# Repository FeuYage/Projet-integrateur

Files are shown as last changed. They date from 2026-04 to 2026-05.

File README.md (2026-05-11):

# Projet Trottinette électrique

Ce projet est concu conjointement par Jérémy Roy, Arthur Méot, l'équipe professorale du 
Cégep de Sherbrooke et Écomobilité Sherbrooke par l'intermédiaire de M.Gauthier

L'objectif est la création d'un tableau de bord à l'aide d'un PCB de notre conception faisant
le lien entre le controlleur d'une trottinette électrique et un Rasberry Pi 3 servant à l'affichage sur un 
écran HDMI.

Ce projet a pour but de permettre aux étudiants de travailler sur un système réel et intégré plutôt que 
sur des montages de laboratoire isolés et théorique.

## Fonctionnalités requises
Le projet devra présenter les aspects suivant tel qu'exigé par Écomobilité Sherbrooke:
- L'affichage en temps réel des données en provenance de la trottinette
- Une interface ergonomique 
- Fixation au guidon par un boitier imprimé en 3D
- Présence d'un manuel utilisateur
- Restrictions de composantes imposé par le client. (Voir prérequis)

## Prérequis

### Matériel
- Base de trottinette fonctionnel fournit par le client
- Rasberry Pi 3
- Écran compatible avec la communication HDMI (Rasberry Pi)
- Cable JST 10 pins à JST 10 pins (PCB STM32)
- Cables à breadboard femelle à femelles (PCB STM32 / Rasberry Pi)
- PCB concu par les étudiants (PCB STM32)
- Boitier fixable sur le guidon de la trottinette (Boitier 3D)

### Logiciel
- Grisement lors du freinage (Rasberry Pi)
- Affichage du mode de conduite (Rasberry Pi)
- Arrêt de l'accélération moteur lors du freinage (Rasberry Pi)
- Affichage en temps réel des données (Rasberry Pi)
- Interface ergonomique (Rasberry Pi)
- Réception données sous format UART (STM32)

### Limitations
- Le PCB doit être programmable par le connecteur USB-C
- Nous devons avoir un bouton reset dédié sur le PCB
- Nous devons utiliser la puce STM32U083MC 
- Power supply 5V de 2.5A pour l'alimentation du Rasberry Pi 4 model B
- Les Dels utiliser doivent utiliser de 5mA
- Alimentation maximale de 12V/0.5A
- La réception des données se fait par le format JSON sur un protocol UART en provenance du controleur 
- Dût à notre installation actuelle avec un écran HDMI, la station et fixe et ne peux pas être fixé sur la trottinette
- Le système ne possède présentement pas de sécurité en cas de chute qui stopperait le moteur.
- Le système ne peut fonctionner sur l'alimentation de la batterie car il n'y a plus de convertisseur à la sortie du 12V.

## Structure

### Schéma
Voir section "PCB" -> "Schémas" pour voir les schémas de concept et électrique du projet.

### Dossiers/codes
Voir section "Codes" pour visionner les codes nécessaire au fonctionnement du projet.
#### Section Rasberry Pi 
- Ce code est à insérer dans un Rasberry Pi 4 model B et sert à l'affichage des données traitées par le STM32 sous format UART ou I2C sur un écran par l'intermédiaire d'un port HDMI.
#### Section STM32
- Ce code est à insérer dans le module STM32 conçu pour ce projet est fait le traitement des données reçu en provenance du controlleur de la trottinette.  Il recoit des informations par UART sous le format JSON et les retourne par UART et I2C.  

### Tests/validation
[Plan_Test](https://github.com/FeuYage/Projet-integrateur/tree/main/PCB/Plan%20de%20test)

## Utilisation

### Pour un utilisateur
- Lors du démarrage, passage par 2 modes : initialisation / mode conduite.
- En mode conduite, l'utilisateur à accès à : Freins / Accélération / Interrupteur des lumières / Informations affichées sur l'écran (Vitesse en km/h, niveau charge batterie, état freins, indicateur de la clé, température drive, mode de vitesse, état lumière, état arrêt urgence)
- L'utilisateur n'a pas d'accès aux éléments de débuggages.

### Pour un developpeur
- Mettre le jumper sur les broches BOOT du PCB pour entrer dans le mode de démarrage programmation par USB OU, Brancher le port JTAG pour programmation.
- Programmation faite par l'intermédiaire du port USB-C ou JTAG du PCB fait par les étudiants et en passent par la logiciel CUBEIDE pour modification du code accessible dans la section STM32.
- Plusieurs éléments de débuggages sont présent sur le PCB pour diagnostiquer toutes erreurs possibles.  Les dels servent pour la vérification de l'alimentation avec les points de test et des broches Arduino sont accessible pour analyse avec un analyseur logique.
- Il est également possible d'ajouter de nouvelles fonctionalités à l'interface en modifiant le code dans la section Rasberry Pi du GitHub.

### Prochaines étapes (todo)
- Ajout d'une centrale inertielle pour sécurité aditionnelle.
- Conception d'un boitier fermé pour fixation sur guidon.
- Ajout d'un régulateur 12V pour permettre l'alimentation par le controlleur de la trottinette.
- Conversion du code pour communication avec interrupts.

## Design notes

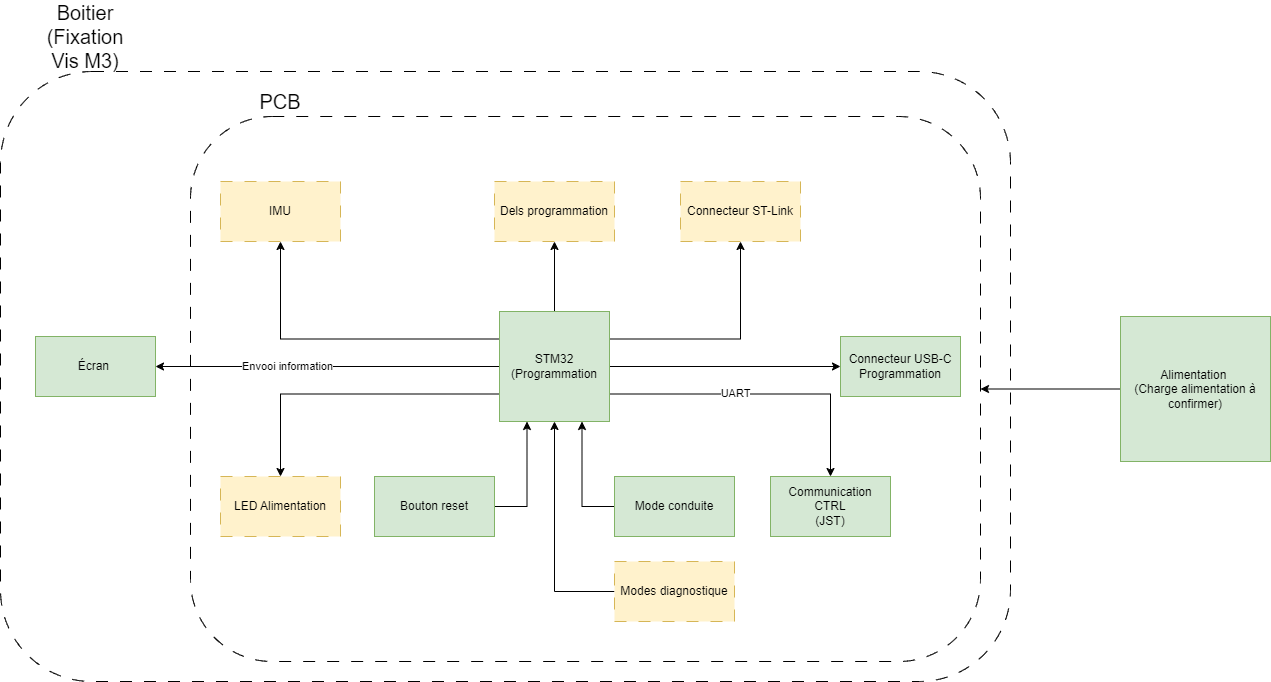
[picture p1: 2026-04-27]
PCB/Schémas/Schéma concept.png

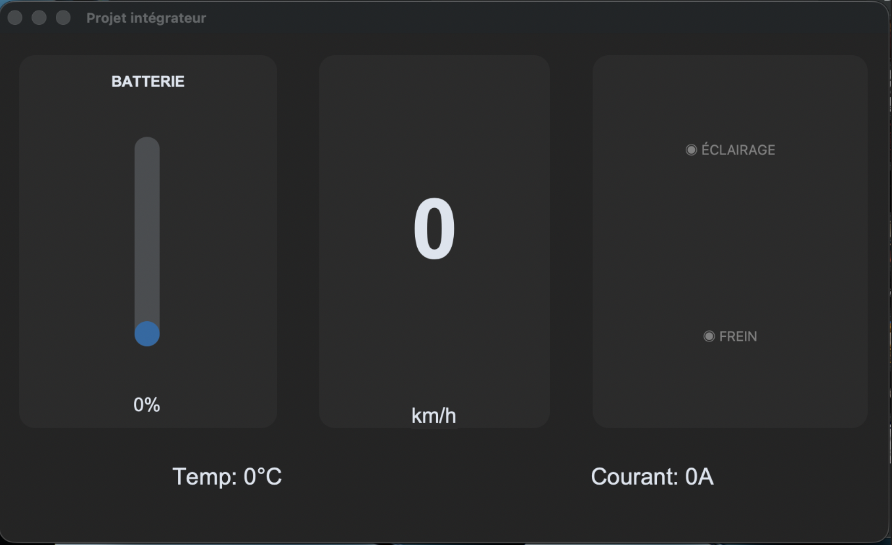
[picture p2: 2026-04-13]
Code/Rasberry Pi/image.png

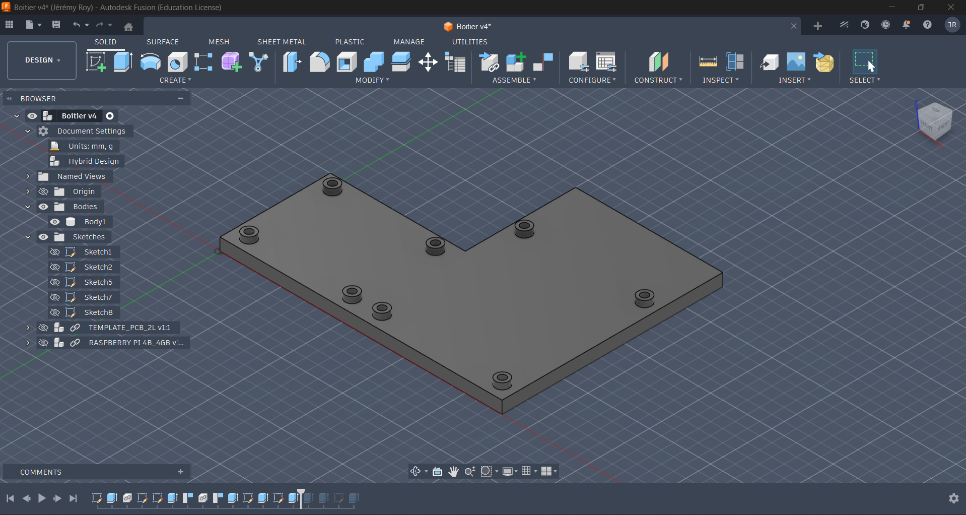
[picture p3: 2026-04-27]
Modèle 3D/Rendering/Jérémy_Roy_Projet_Trottinette.png

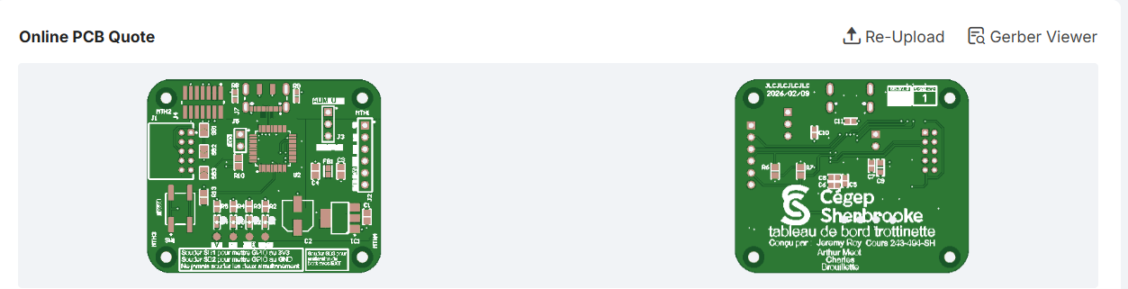
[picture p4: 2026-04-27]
PCB/Rendering/JLCPCB.png

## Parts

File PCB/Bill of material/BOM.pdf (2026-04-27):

Comment | Description | Designator | Footprint | LibRef | Quantity
0.1µF | CAPCER0.1UF50V X7R0603 | C? | CAP0603_1608 | C0603C104K5RAC786 7 | 3
1µF | CAPCER1UF50VX5R 0603 | C? | CAP0603_1608 | C1608X5R1H105K080 AB | 2
4.7µF | CAPCER4.7UF25V X5R0603 | C? | MURATAGRM188 0603_1608 | GRM188R61E475KE11 D | 1
10µF | CAPCER10UF25V X5R0805 | C? | CAP0805_2012 | 08053D106MAT2A | 3
100µF | CAPALUM100UF20% 25VSMD | C? | CAPALSMD6.6MM H7.7MM | UCL1E101MCL1GS | 1
10000pF | CAPCER10000PF50V X7R0603 | C? | CAP0603_1608 | C0603C103K5RAC786 7 | 1
Green | LEDGREENCLEAR CHIPSMD | D? | LED0603_1608 GREEN | LTST-C193KGKT-5A | 4
BLM18KG121TZ1D | ChipFerriteBead Array, 0603, 120Ω@ 100MHz, 25%, 0.03Ω, 3A | FB? | FP-BLM18-0_15-t0_6-d1_2-IPC_B | CMP-06046-002016-1 | 1
NCP1117LPST33T3G | ICREGLINEAR3.3V1A SOT223 | IC? | ONSEMISOT-223 ST(318H) | NCP1117LPST33T3G | 1
532610671 | CONNHEADERSMD R/A6POS1.25MM | J? | MOLEX_532610671 | CMP-005-000032-2 | 1
Cavalier_1x2 | Interconnection Device | J? | SNT-100-BK-T-H-Footprint-1 | CMP-005-000025-2 | 1
CON_HDR_1X2 | CON- Header 1x2pins 100mil -TH | J? | CON_HDR_1x2 | CMP-005-000000-2 | 1
DX07S016JA1R1500 | CONNRCPUSB2.0 TYPC24PSMDRA | J? | FP-DX07S016JA1R1500-MFG | CMP-19038-000003-1 | 1
FTSH-107-01-L-DV-K | CONNHEADERSMD 14POS1.27MM | J? | FP-FTSH-107-01-L-DV-K-MFG | CMP-02766-001412-1 | 2
M50-3502042 | 1.27mm(0.05)Pitch DILVertical ThroughboardPin Header, selectivegold +tin, 20+20contacts | J? | HARWIN_M50-3502042 | M50-3502042 | 1
S10B-PHDSS(LF)(SN) | CONNHEADERR/A 10POS2MM | J? | FP-S10B-PHDSS_LF_SN-MFG | CMP-17439-000374-2 | 2
STD35P6LLF6 | P-Channel 60V35A (Tc) 70W(Tc)Surface Mount DPAK | Q? | DPAK228P987X240-3N | CMP-00003-2 | 1
2kOhms | RESSMD2KOHM1% 1/10W0603 | R? | RES0603_1608 | ERJ-3EKF2001V | 1
5.1kOhms | RESSMD5.1KOHM 1%1/10W0603 | R? | YAGEORES 0603_1608 | AC0603FR-075K1L | 2
10kOhms | RES10KOHM1% 1/4W0805 | R? | RES0805_2012 | RNCP0805FTD10K0 | 7
270Ohms | RES270OHM1% 1/10W0603 | R? | RES0603_1608 | RMCF0603FT270R | 1
604Ohms | RES604OHM1% 1/10W0603 | R? | RES0603_1608 | RMCF0603FT604R | 2
EVQ-Q2U01W | SWITCHTACTILESPST-NO0.02A15V | SW? | FP-EVQ-Q2U01W-MFG | CMP-05618-000050-1 | 1
LM66100DCKT | ICORCTRLRIDEAL DIODESC70-6 | U? | FP-DCK0006A-IPC_C | CMP-04910-000059-1 | 1
STM32U083CCT6 | MCU32-bit ARM CortexM0+RISC 256KBFlash2.5V/3.3V 48-PinLQFPTray | U? | STM32U083CCT6-Footprint-1 | CMP-005-000031-1 | 2

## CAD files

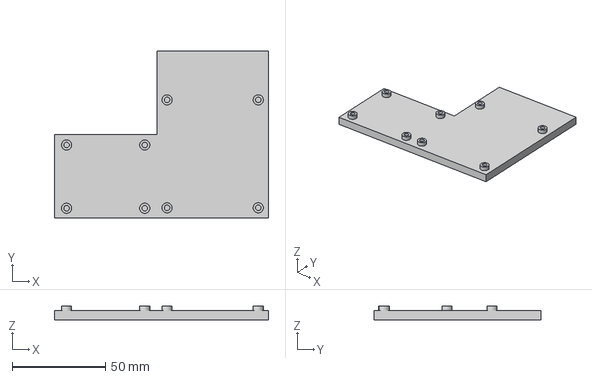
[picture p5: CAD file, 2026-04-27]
Modèle 3D/Impression 3d/Jérémy_Roy_Projet_Trottinette.3mf
115.0 x 90.0 x 7.50 mm

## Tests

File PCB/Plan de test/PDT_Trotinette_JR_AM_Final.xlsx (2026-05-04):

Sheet: Tests
 | Plan de tests
Nom du PCB | Tableau de bord trottinette | Préparé par | Jérémy Roy
Cours | Projet intégrateur 2 | Testeur | Jérémy Roy
Département | Technologies du génie électrique | date | 2026-04-05
Révision du PCB | 1.00
Fonction | Description du test | Résultat | Raison réussite ou échec | modification effectuée | Nouveau résultat | Commentaire
Intégration | Avant la soudure, tester si des vis M2 entrent bien dans les trous de montage | Réussi | Les vis passent bien dans les trous du PCB et sont suffisament longue pour tenir celui-ci dans le boitier 3D
Unitaire | Vérifier s'il est possible de connecter le fil JST 10 broches dans le connecteur J1 | Réussi | Le connecteur passe bien et n'accroche pas
Unitaire | Vérifier s'il est possible de connecter le JTAG dans son connecteur | Réussi | Le fil se connecte sans problème et la broche 1 du fil correspond bien avec la broche 1 du connecteur identifié par un point blanc sur le PCB
Intégration | Vérification visuelle de la carte pour confirmer qu'aucune composantes n'est mal soudé. | Réussi | Aucune composante ne semble mal soudé ou présente des ponts de soudure. Pas de composantes en tombstone
Unitaire | Avec le multimètre, mesurez la résistance entre le point de test USB et l'extérieur du connecteur USB (La résistance devrait etre dans l'ordre des k ohm) | Réussi | Résistance de 2.79Mohm détecté avec le multimètre
Unitaire | Avec le multimètre, mesurez la résistance entre le point de test VPI et l'extérieur du connecteur USB (La résistance devrait etre dans l'ordre des k ohm) | Réussi | Résistance surpassant la limite du multimètre détecté (Aucun court-circuit)
Unitaire | Avec le multimètre, mesurez la résistance entre le point de test 5V et l'extérieur du connecteur USB (La résistance devrait etre dans l'ordre des k ohm) | Réussi | Résistance de 1.89Mohm entre le point de test 5V et le GND
Unitaire | Avec le multimètre, mesurez la résistance entre le point de test 3V3 et l'extérieur du connecteur USB (La résistance devrait etre dans l'ordre des k ohm) | Échec | Court-circuit entre le point de test 3V3 et le GND mesuré sur le dessus du connecteur USB-C (Les trous imprévus fait par JLCPCB sont réellement des vias et causent un court circuit) | Driller les trous avec une perceuse à colonne afin de retirer le metal à l'intérieur des vias et briser la connexion. | Résistance de 3.647k ohm entre le 3V3 et le GND | Erreur en exportant les gerbers a causé ces trous. En reproduisant les
Unitaire | Avec le multimètre en mode continuité, confirmé qu'il n'y a pas de chemin entre les points de test USB et VPI et entre 5V et 3V3 | Réussi | Tester la continuité entre les alimentations et il n'y a pas de court-circuit. Fait le test en mettant le jumper vers USB et le 5V et ALIM_USB deviennent connecté. Même chose avec le ALIM_PI.
Unitaire | Tester l'orientation des dels D1 à D4 en placant la sonde rouge sur les points de test de chaque diode et la sonde noir sur le pad en direction de la résistance. | Réussi | Les DELs s'allument tous lorsque testé en mode diode avec le multimètre mais la diode D4 semble faible
Intégration | Tester le fonctionnement de la switch de reset avec le multimètre en mode continuité entre deux broches adjacentes et appuyer sur l'interrupteur. (Une fois appuyé, il devrait y avoir de la continuité) | Réussi | Les broches ne sont pas connecté ensemble tant que le bouton n'est pas appuyé mais devient connecté lorsque le bouton est appuyé.
Intégration | Mettre un jumper sur le bornier J3 entre la broche du milieu et l'indicateur ALIM_USB puis, brancher la carte et mesurer la tension entre les points USB / 5V / 3V3 et l'extérieur du connecteur USB. (La valeur du point de test USB devrait etre d'environ 5V et le 3V3 devrait se situer entre 3.2 et 3.4V) | Réussi | Tension de 3.29V mesuré sur le point de test 3V3 et tension de 4.88 mesuré sur le point de test 5V et USB
Intégration | Mettre un jumper sur le bornier J3 entre la broche du milieu et l'indicateur ALIM_PI puis, brancher la carte et mesurer la tension entre les points VPI / 5V / 3V3 et l'extérieur du connecteur USB. (La valeur du point de test VPI devrait etre d'environ 5V et le 3V3 devrait se situer entre 3.2 et 3.4V) | Réussi | Il est possible d'alimenter le circuit par l'alimentation du rasberry Pi avec une tension de 3.29V sur le point de test 3V3 et 4.95V sur le point de test 5V
Intégration | Vérifier si les diodes D1 à D4 s'allument selon le mode d'alimentation sélectionné avec le bornier J3 | Réussi | L'interface CUBEIDE arrive à se connecter au circuit et à transmettre le code dans le PCB
Fonctionnel | Brancher le connecteur ST-Link et alimenter en mode USB pour ouvrir CUBEIDE et confirmer s'il est possible de communiquer avec le circuit. | Échec | Le PCB n'est jamais détecté par l'interface | Activation des options flash dans CUBEMX afin de permettre le controle du mode BOOT avec la broche BOOT0 | Échec | L'option NOE du debug USB ne peut être activé en même temps que SWD ce qui bloque la communication.
Fonctionnel | Récuperer information sur format UART en provenance du Rasberry pi | Échec | Il est possible de visionner les informations mais très bruité à cause du cable. À retester mais souder directement sur les broches pour bypasser le fil. | Soudure de fils directement sur les broches du connecteur pour eviter le bruit du cable fournit par enseignant. | Échec | Le code bloquant empêche la bonne lecture du message recu par l'interface UART2 vers UART1 ***Il faudrait faire une nouvelle version avec un code utilisant des interrupts***
Fonctionnel | Récuperer information sur format I2C en provenance du Rasberry pi | Échec | Fonctionalité non testable par manque de temps lors de la programmation. | Pas eu le temps | Échec | Pas eu le temps
Unitaire | Vérfication de l'installation préalable de CustomTkinter sur le Rasberry | Échec | CustomTkinter était mal installé, il manquait des fichiers | J'ai résintallé correctement Tkinter sur le Raspberry | Réussi
Unitaire | Branchement du module JSON sur le Raspberry Pi 3 avec la liaison UART | Réussi | Les vis passent bien dans les trous du PCB et sont suffisament longue pour tenir celui-ci dans le boitier 3D
Fonctionnel | Vérification de la réception d'un JSON sur le rasberry Pi 3 via minicom | Échec | Il faut brancher le GND également du module JSON au Raspberry Pi | J'ai branché le GND au raspberry | Réussi
Intégration | Lancement du code Tkinter à fin de visualiser le changement des valeurs sur l'interface | Échec | Les nom des variables JSON dans le code ne correpondent avec celle envoyé par le module JSON | J'ai modifié les nom des variables pour les faire correspondre | Réussi
Unitaire | Vérification de l'impossibilité de freiner et accèlerer en même temps | Réussi | Les 2 variables ne peuvent pas s'activer au même moment
Unitaire | Affichage de toutes les statistiques demandées (vitesse, freinage, température, lumière, courant, batterie) | Réussi | Les valeurs s'affichent bien et changent toutes les 200ms
Unitaire | Grisement de l'écran lors du feinage | Échec | La fonction qui s'occupe de ca n'a pas été implémenté sur le nouveau code après le changement de nom des variables
Intégration | Vérification visuelle que l'interface est bien ergonomique et compréhenseible pour un utilisateur lambda | Réussi | Les informations sont bien visbiles, compréhensible et bien dispositionner sur l'écran

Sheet: Modification 2ième version
# | Modification suggérée | Explication | Column1
1 | Ajout DELS sur GPIO | Test du bouton reset visuel avec circuit alimenté
2 | Ajout de DELs sur les trames de communication UART | Visualisation rapide du fonctionnement de la trame UART
3 | Contrôle automatique du mode d'alimentation | Pas d'erreur humaine lors des phases de test à l'ordinateur et avec modules externe pour alimentation
4 | Code UART en continue | Le code bloquant empêche la transmission parfaite du message envoyé dans le PCB. Il faudrait donc le refaire à nouveau
5 | Code I2C en continue | Le code bloquant empêche la transmission parfaite du message envoyé dans le PCB. Il faudrait donc le refaire à nouveau
6 | Grisement lors du freinage | Pas d'indication du fonctionnement du frein.
7 | Ajout des modes de débuggages dans le PI | Pas de possibilités de voir les bugs sauf en étant connecté sur l'ordinateur avec le ST-LINK
8
9
10
11
12
13

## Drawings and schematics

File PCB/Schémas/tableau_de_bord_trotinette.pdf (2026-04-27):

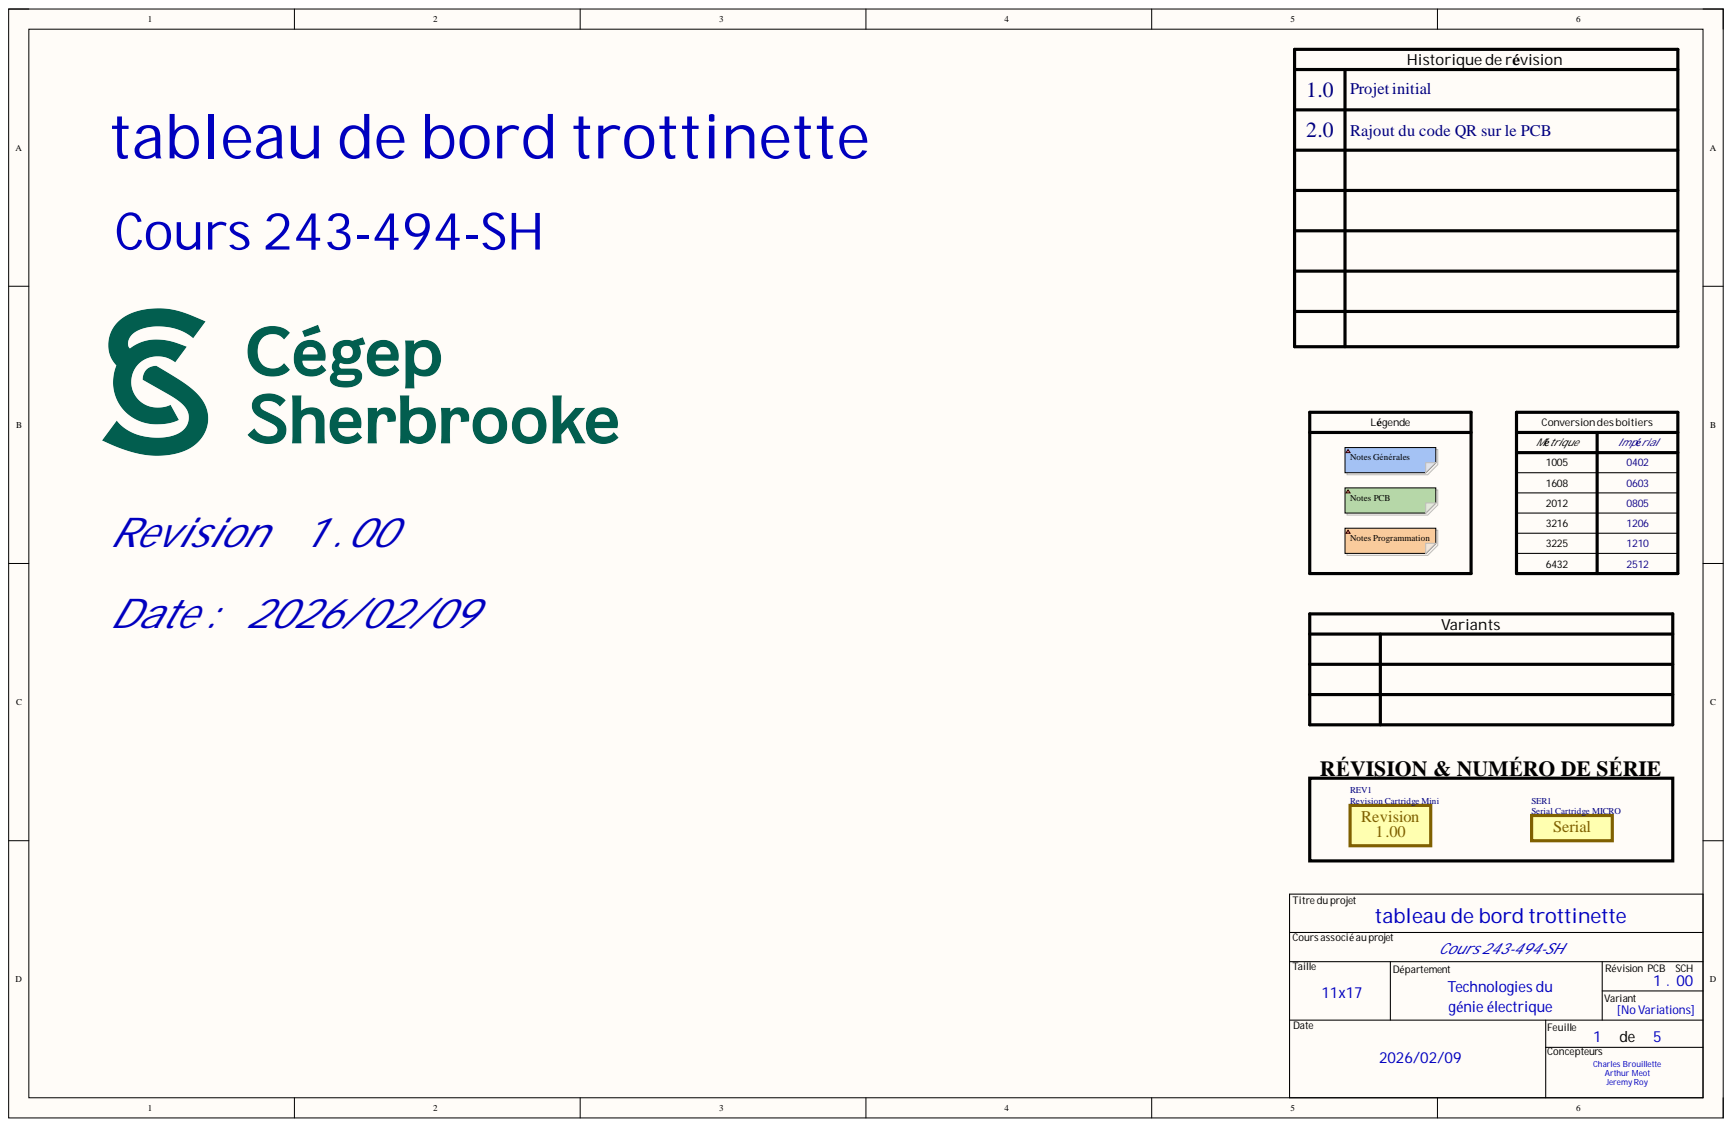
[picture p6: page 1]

1.0 | Pr ojet i n i t i al

2.0 | Raj o u t d u co de Q R su r le PC B

1005 | 0402
1608 | 0603
201 2 | 0805
321 6 | 1206
322 5 | 121 0
643 2 | 251 2

tableau de bord trottinett

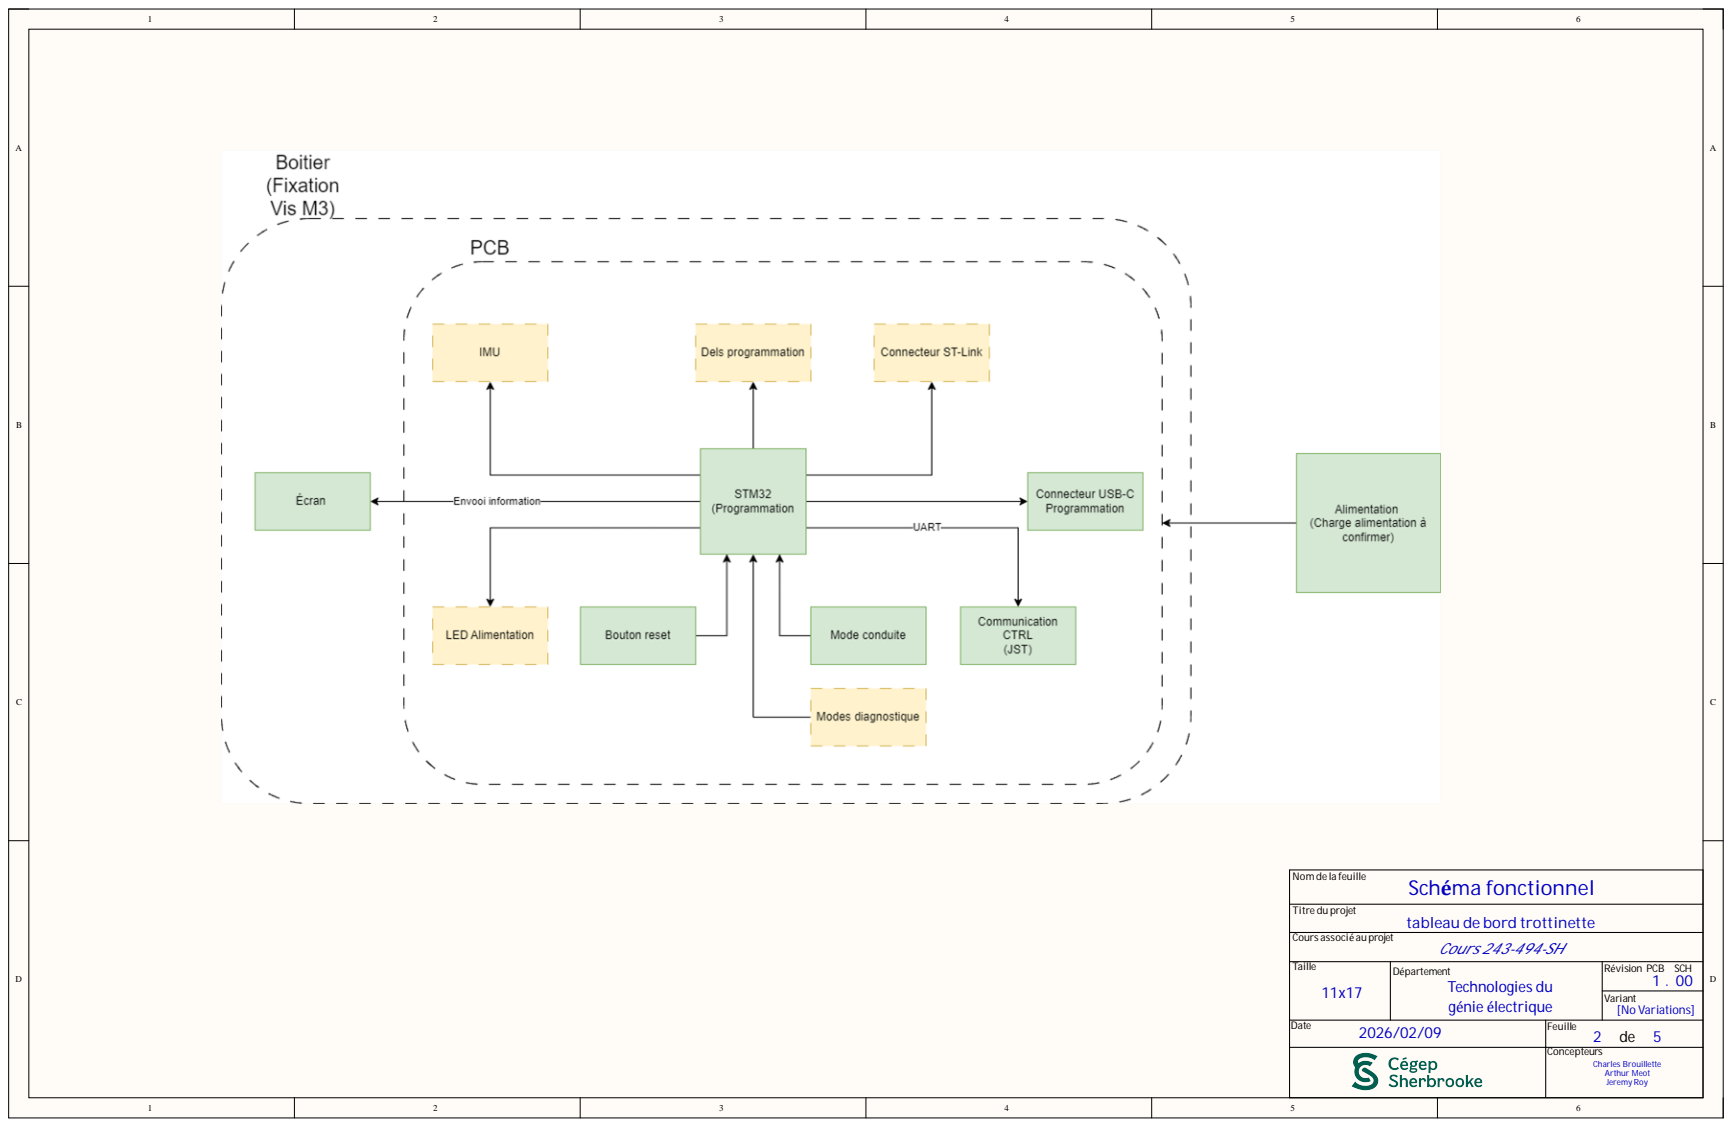
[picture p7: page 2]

Nom de la feuille

Titre du projet
tableau de bord trottinette Cours associé au projet

Date 2026/02/09 | Feuille 2 de Concepteurs 5

Charles Brouillette Arthur Meot Jeremy Roy

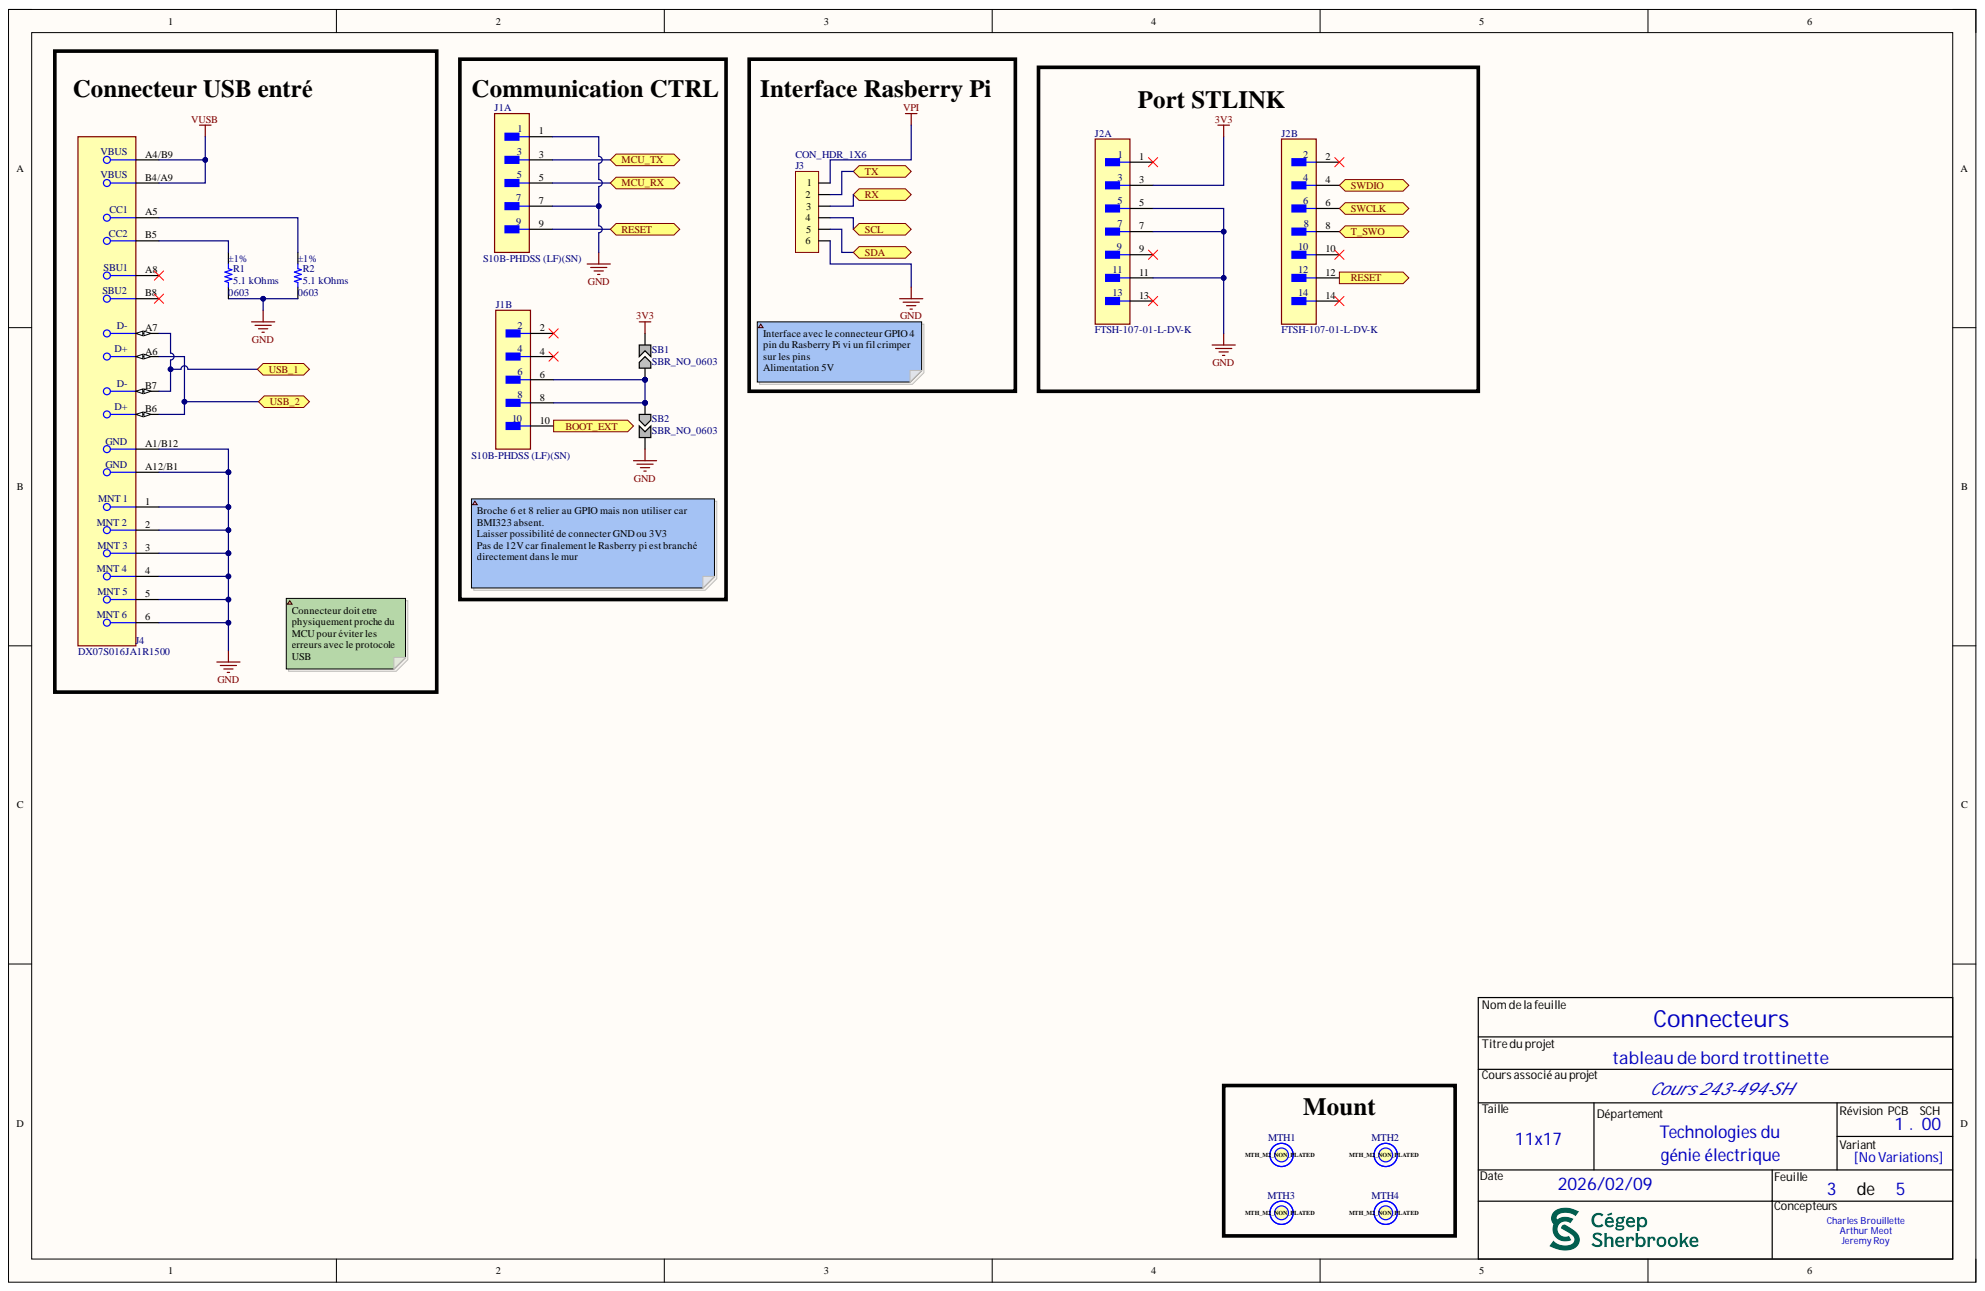
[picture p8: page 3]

Interface avec le connecteur GPIO 4
pin du Rasberry Pi vi un fil crimper
sur les pins
Alimentation 5V

Broche 6 et 8 relier au GPIO mais non utiliser car
BMI323 absent.
Laisser possibilité de connecter GND ou 3V3
Pas de 12V car finalement le Rasberry pi est branché
directement dans le mur

Connecteur doit etre
physiquement proche du
MCU pour éviter les
erreurs avec le protocole
USB

Nom de la feuille

Titre du projet
tableau de bord trottinette Cours associé au projet

Date 2026/02/09 | Feuille 3 de Concepteurs 5

Charles Brouillette Arthur Meot Jeremy Roy

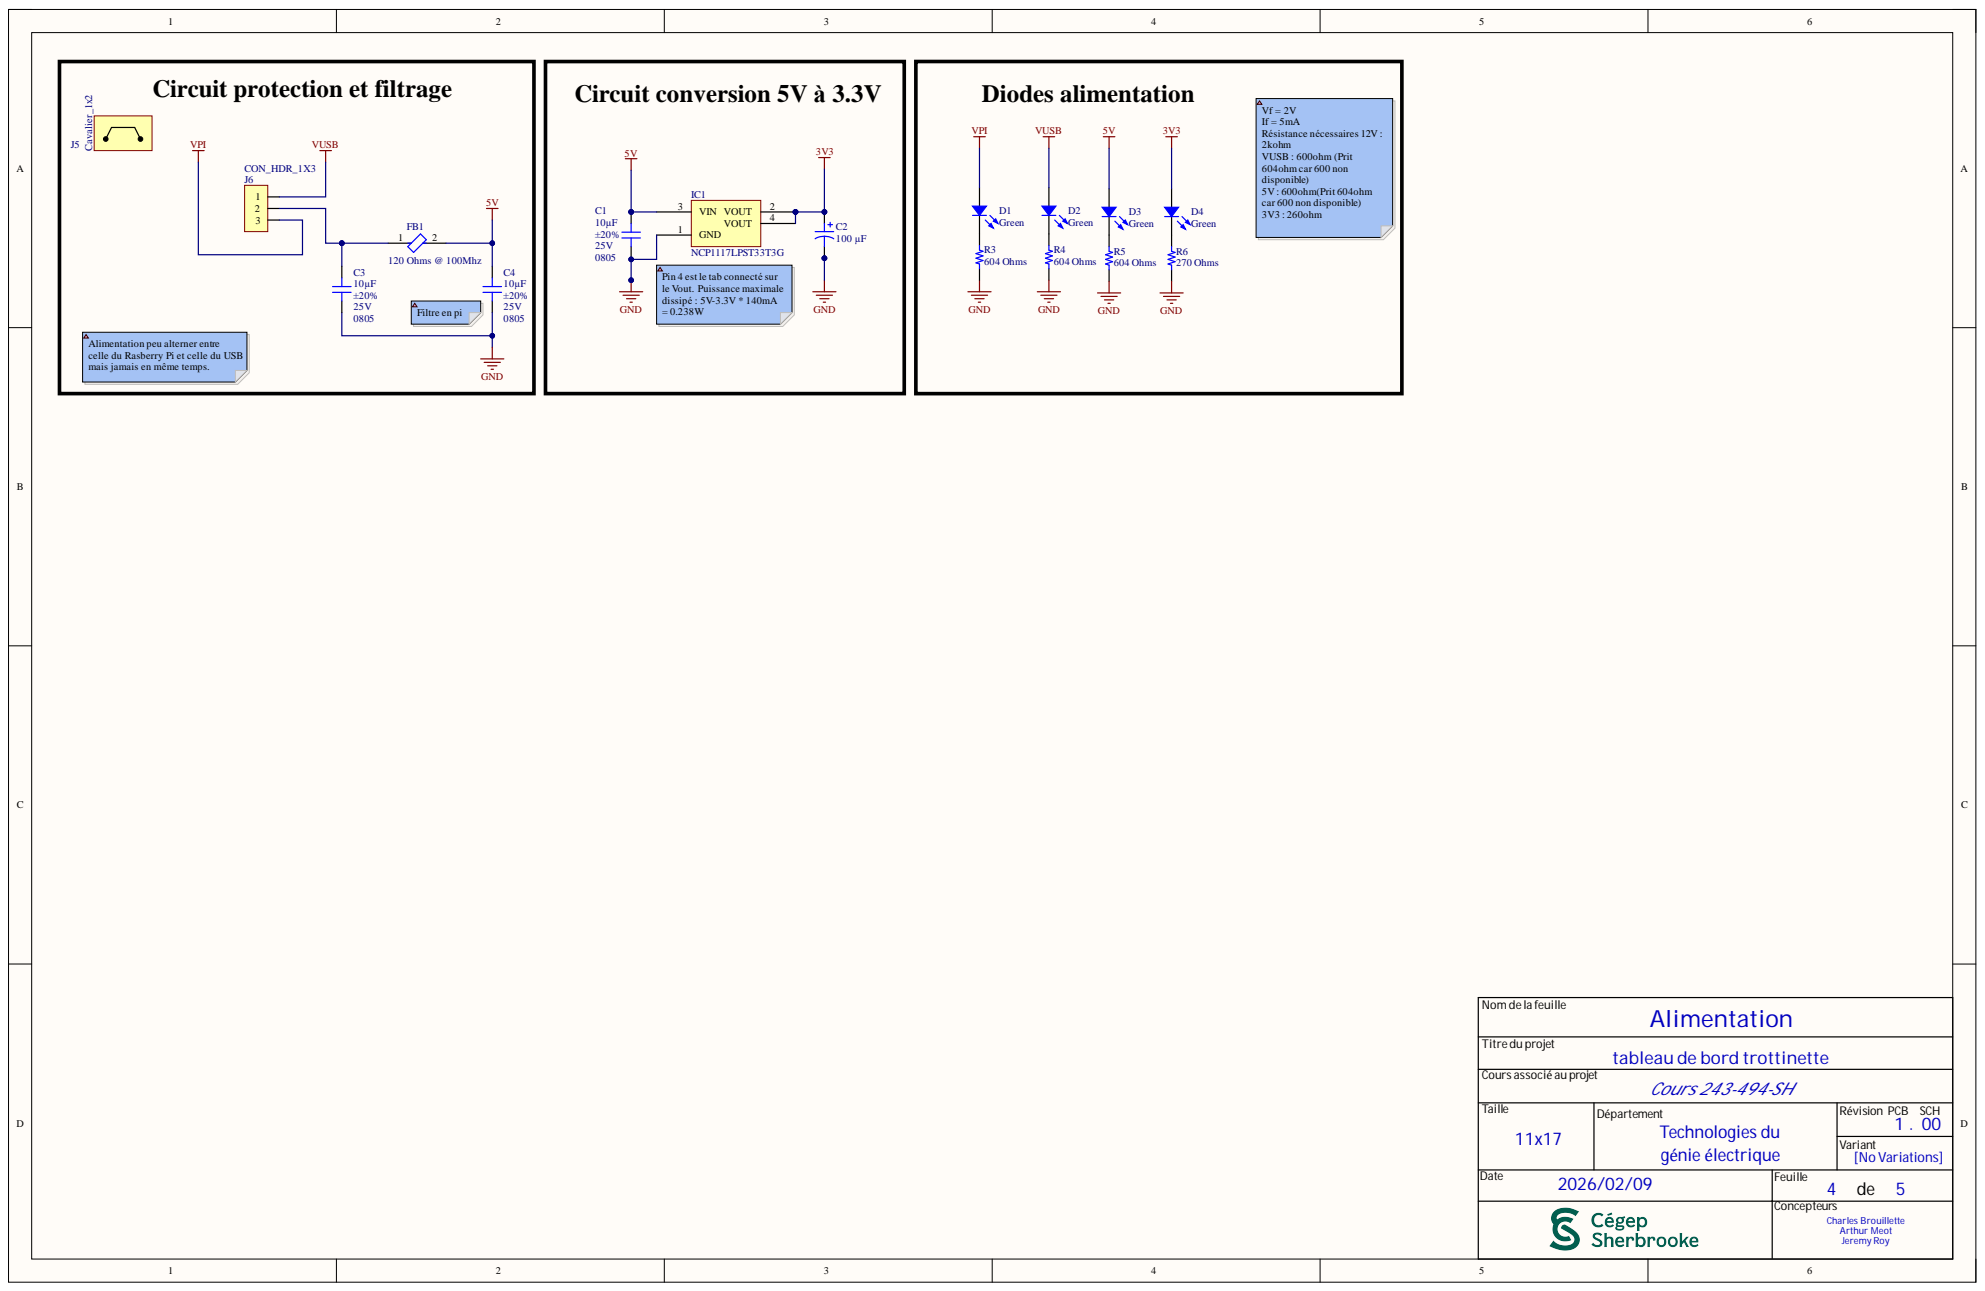
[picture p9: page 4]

D a te 2026/02/09 | F eui l l e 4 de 5

Concepteu rs Ch a r l es B r o u i l l e tte Ar th u r Me o t Je r e my Ro y

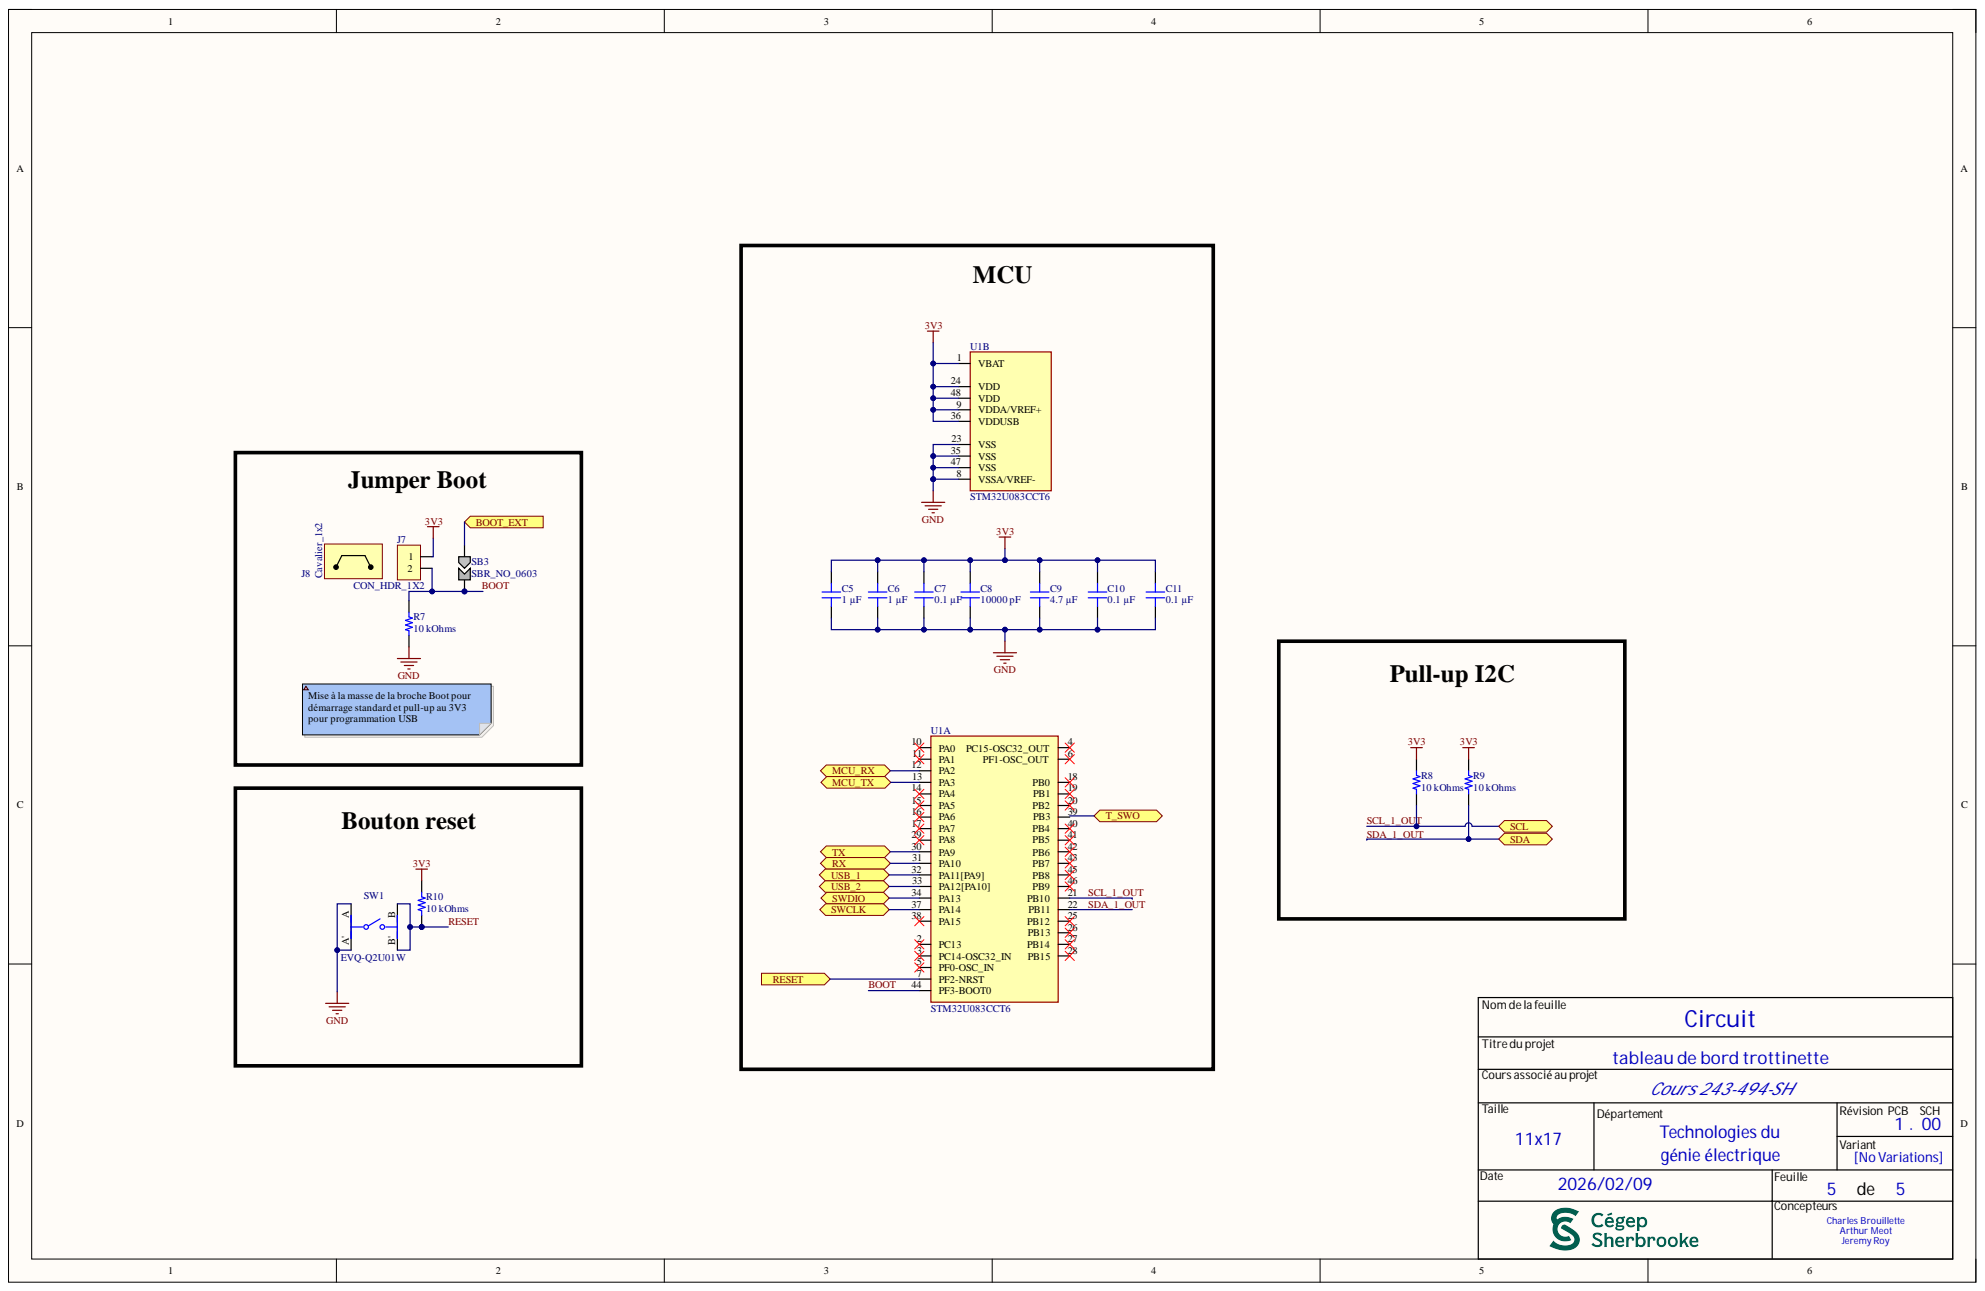
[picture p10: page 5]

VDD 24
VDD 48
VDDA/VREF+ 9
VDDUSB 36

VSS 35

VSSA/VREF- 8

Mise à la masse de la broche Boot pour
démarrage standard et pull-up au 3V3
pour programmation USB

Nom de la feuille

Titre du projet
tableau de bord trottinette Cours associé au projet

Date 2026/02/09 | Feuille 5 de Concepteurs 5

Charles Brouillette Arthur Meot Jeremy Roy

Comment | Description | Designator | Footprint | LibRef | Quantity
10µF | CAPCER10UF25V X5R0805 | C1, C3, C4 | CAP0805_2012 | 08053D106MAT2A | 3
100µF | CAPALUM100UF20% 25VSMD | C2 | CAPALSMD6.6MM H7.7MM | UCL1E101MCL1GS | 1
1µF | CAPCER1UF50VX5R 0603 | C5, C6 | CAP0603_1608 | C1608X5R1H105K080 AB | 2
0.1µF | CAPCER0.1UF50V X7R0603 | C7, C10, C11 | CAP0603_1608 | C0603C104K5RAC786 7 | 3
10000pF | CAPCER10000PF50V X7R0603 | C8 | CAP0603_1608 | C0603C103K5RAC786 7 | 1
4.7µF | CAPCER4.7UF25V X5R0603 | C9 | MURATAGRM188 0603_1608 | GRM188R61E475KE11 D | 1
Green | LEDGREENCLEAR CHIPSMD | D1, D2, D3, D4 | LED0603_1608 GREEN | LTST-C193KGKT-5A | 4
BLM18KG121TZ1D | ChipFerriteBead Array, 0603, 120Ω@ 100MHz, 25%, 0.03Ω, 3A | FB1 | FP-BLM18-0_15-t0_6-d1_2-IPC_B | CMP-06046-002016-1 | 1
NCP1117LPST33T3G | ICREGLINEAR3.3V1A SOT223 | IC1 | ONSEMISOT-223 ST(318H) | NCP1117LPST33T3G | 1
S10B-PHDSS(LF)(SN) | CONNHEADERR/A 10POS2MM | J1 | FP-S10B-PHDSS_LF_SN-MFG | CMP-17439-000374-2 | 1
FTSH-107-01-L-DV-K | CONNHEADERSMD 14POS1.27MM | J2 | FP-FTSH-107-01-L-DV-K-MFG | CMP-02766-001412-1 | 1
CON_HDR_1X6 | CON- Header 1X6 pins, 100Mils - TH-6 | J3 | CON_HDR_1X6 | CMP-005-000003-1 | 1
DX07S016JA1R1500 | CONNRCPUSB2.0 TYPC24PSMDRA | J4 | FP-DX07S016JA1R1500-MFG | CMP-19038-000003-1 | 1
Cavalier_1x2 | Interconnection Device | J5, J8 | SNT-100-BK-T-H-Footprint-1 | CMP-005-000025-2 | 2
CON_HDR_1X3 | CON- Header 1x3pins-100Mils - TH | J6 | CON_HDR_1x3 | CMP-005-000001-1 | 1
CON_HDR_1X2 | CON- Header 1x2pins 100mil -TH | J7 | CON_HDR_1x2 | CMP-005-000000-2 | 1
5.1kOhms | RESSMD5.1KOHM 1%1/10W0603 | R1, R2 | YAGEORES 0603_1608 | AC0603FR-075K1L | 2
604Ohms | RES604OHM1% 1/10W0603 | R3, R4, R5 | RES0603_1608 | RMCF0603FT604R | 3
270Ohms | RES270OHM1% 1/10W0603 | R6 | RES0603_1608 | RMCF0603FT270R | 1
10kOhms | RES10KOHM1% 1/4W0805 | R7, R8, R9, R10 | RES0805_2012 | RNCP0805FTD10K0 | 4
EVQ-Q2U01W | SWITCHTACTILESPST-NO0.02A15V | SW1 | FP-EVQ-Q2U01W-MFG | CMP-05618-000050-1 | 1
STM32U083CCT6 | MCU32-bit ARM CortexM0+RISC 256KBFlash2.5V/3.3V 48-PinLQFPTray | U1 | STM32U083CCT6-Footprint-1 | CMP-005-000031-1 | 1

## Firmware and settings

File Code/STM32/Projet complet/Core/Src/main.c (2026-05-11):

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
/* Includes ------------------------------------------------------------------*/
#include "main.h"
#include "flash.h"
#include "i2c.h"
#include "usart.h"
#include "usb.h"
#include "gpio.h"

/* USER CODE BEGIN Includes */
#include <string.h>
#include <stdio.h>
/* USER CODE END Includes */

/* USER CODE BEGIN PD */
#define RX_BUFFER_SIZE 256
/* USER CODE END PD */


/* USER CODE BEGIN PV */
char rx_buffer[RX_BUFFER_SIZE];
uint16_t rx_index = 0;
char Message[20] = {"\0"};
uint8_t uart1_rx;
uint8_t uart2_rx;
/* USER CODE END PV */

void SystemClock_Config(void);
/**
  * @brief  The application entry point.
  * @retval int
  */
int main(void)
{

  /* MCU Configuration--------------------------------------------------------*/

  /* Reset of all peripherals, Initializes the Flash interface and the Systick. */
  HAL_Init();

  /* Configure the system clock */
  SystemClock_Config();

  /* Initialize all configured peripherals */
  MX_GPIO_Init();
  MX_I2C2_Init();
  MX_USART1_UART_Init();
  MX_USART2_UART_Init();
  MX_USB_PCD_Init();
  MX_FLASH_Init();
  /* Infinite loop */
  /* USER CODE BEGIN WHILE */
  while (1)
  {
    /* USER CODE END WHILE */

    /* USER CODE BEGIN 3 */
	  // Start reception
	  /*HAL_UART_Receive_IT(&huart1, &uart1_rx, 1);
	  HAL_UART_Receive_IT(&huart2, &uart2_rx, 1);*/

	  uint8_t byte;

	  if(HAL_UART_Receive(&huart2, &byte, 1, 1) == HAL_OK)
	  {
		  HAL_UART_Transmit(&huart1, &byte, 1, HAL_MAX_DELAY);
	  }
	  /*strcpy(Message, "INVALIDE\n\r");
	  HAL_UART_Transmit(&huart1,(uint8_t*)Message , 15, 100);
	  HAL_Delay(2000);*/
  }
  /* USER CODE END 3 */
}

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
/* USER CODE BEGIN 4 */
// Callback function
void HAL_UART_RxCpltCallback(UART_HandleTypeDef *huart) {
  if (huart->Instance == USART1) {
    HAL_UART_Transmit(&huart2, &uart1_rx, 1, 10);
    HAL_UART_Receive_IT(&huart1, &uart1_rx, 1); // Re-enable
  } else if (huart->Instance == USART2) {
    HAL_UART_Transmit(&huart1, &uart2_rx, 1, 10);
    HAL_UART_Receive_IT(&huart2, &uart2_rx, 1); // Re-enable
  }
}

/* USER CODE END 4 */
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


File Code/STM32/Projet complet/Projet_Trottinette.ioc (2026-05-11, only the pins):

Mcu.UserName=STM32U083CCTx
PA10.Signal=USART1_RX
PA2.Signal=USART2_TX
PA3.Signal=USART2_RX
PA9.Signal=USART1_TX
PB10.Signal=I2C2_SCL
PB11.Signal=I2C2_SDA

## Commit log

2026-04-27 AJout de documentation au projet pour guide utilisateur
    [Jérémy_Roy_Projet_Trottinette.3mf, PDT_Trotinette_JR_AM.xlsx]
2026-04-27 Ajout de séparation des sections
    [Jérémy_Roy_Projet_Trottinette.3mf, PDT_Trotinette_JR_AM.xlsx]
2026-04-27 ajout des séparations du code
2026-04-27 insertion du manuel utilisateur dans la section README
2026-05-04 ajout info test
    [PDT_Trotinette_JR_AM.xlsx]
2026-05-04 remplacement du plan de test
    Ajout de la partie à Arthur
    [PDT_Trotinette_JR_AM.xlsx, PDT_Trotinette_JR_AM_Final.xlsx]
2026-05-11 Ajout fichier code STM32
2026-05-11 Changement nom du fichier de code

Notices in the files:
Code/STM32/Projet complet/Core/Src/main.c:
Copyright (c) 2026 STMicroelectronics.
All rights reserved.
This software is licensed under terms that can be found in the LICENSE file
